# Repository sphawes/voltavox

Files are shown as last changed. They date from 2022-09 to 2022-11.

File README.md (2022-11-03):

# Voltavox
Voltavox is a PCB-based phonograph "badge"!

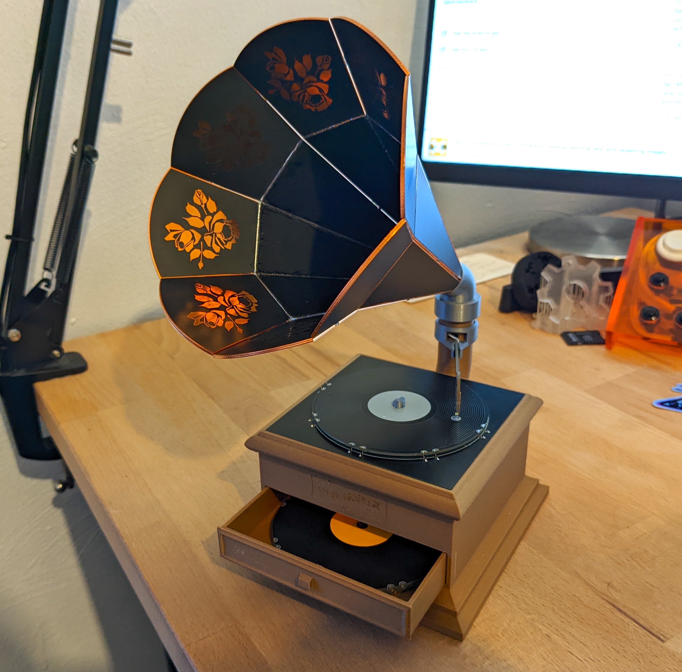
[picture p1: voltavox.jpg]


Made primarially from PCBs, you can take a tiny PCB record, place it on the platter, place the needle on the record, and a song begins to play! Put a different record on, and as expected, you'll get a different song.

Voltavox is based heavily on the [Adafruit Audio FX Sound Board](https://www.adafruit.com/product/2217). Using [arturo182](https://github.com/arturo182)'s [FlexyPins](https://lectronz.com/products/flexypin-pack-of-100) and some castellated edges on the record PCBs, each record selectively pulls a different control pin on the Audio FX board to ground, choosing a different track. Dropping the needle onto the record completes the circuit and starts playing the audio. 
The horn is also comprised of PCBs soldered edge-to-edge, with a small speaker inside.

## BOM
### Off The Shelf
| Item | Quantity |
| ---- | --- |
| [Adafruit Audio FX Sound Board + 2x2W Amp - 16MB](https://www.adafruit.com/product/2217) | 1 |
| [8 Ohm Speaker](https://www.adafruit.com/product/1890) | 1 |
| [1200mAh LiPo Battery](https://www.adafruit.com/product/258) | 1 |
| [Micro-Lipo Charger](https://www.adafruit.com/product/1904) | 1 |
| [FlexyPins](https://lectronz.com/products/flexypin-pack-of-100) | 10 |
| [SPST Slide Switch](https://www.adafruit.com/product/805) | 1 |
| [Silicone Wire - 30AWG](https://www.adafruit.com/product/3169) | 1 |
| [P75-LM3 Spring Pin](https://www.adafruit.com/product/394) | 1 |
| [1x14 2.54mm SMT Header](https://www.digikey.com/en/products/detail/w%C3%BCrth-elektronik/61001418221/4846817) | 2 |
| [1x4 2.54mm SMT Header](https://www.digikey.com/en/products/detail/metz-connect-usa-inc/PM20204VBNN/12342877) | 1 |
| [Adhesive-Backed Green Felt](https://amzn.to/3xrK0NY) | 1 |
| [Dark Wood PLA Filament](https://amzn.to/3QOZQca) | 1 |
| [Record Label Stickers](https://www.amazon.com/dp/B06VX94JD8)| 1 |

### PCBs
| Item | Quantity | Order Instructions | Note |
| ---- | --- | --- | ---- |
| Record | 1+ | 1.6mm PCB, 1oz copper. Gloss Black Soldermask, Lead-Free HASL finish. | Has castellated pads to interface with the FlexyPins. Be sure to include a note to your board shop. | 
| Platter | 1 | 1.6mm PCB, 1oz copper. Matte Black Soldermask, Lead-Free HASL finish. | - |
| Needle | 1 | 1.6mm PCB, 1oz copper. Gloss Black Soldermask, Lead-Free HASL finish. | - |
| Horn Tier 1 | 8 | 1.6mm PCB, 1oz copper. Matte Black Soldermask, ENIG gold immersion finish. | Has castellated edges that are used for structural soldering. Be sure to include a note to your board shop.|
| Horn Tier 2 | 8 | 1.6mm PCB, 1oz copper. Matte Black Soldermask, ENIG gold immersion finish. | Has castellated edges that are used for structural soldering. Be sure to include a note to your board shop.|

### 3D Prints
| Item | Quantity | Material | Note |
| ---- | --- | --- | ---- |
| base | 1 | Wood PLA | Print with supports at 0.2mm layer height, 15% infill or more |
| horn-base-adapter | 1 | Silver PLA | Print with supports at 0.2mm layer height, 20% infill or more |
| drawer | 1 | Wood PLA | Print without supports at 0.2mm layer height, 15% infill or more |
| needle-mount | 1 | Silver PETG | Print without supports at 0.2mm layer height, 20% infill or more |
| pin | 1 | Silver PLA | Print without supports at 0.2mm layer height, 15% infill or more |

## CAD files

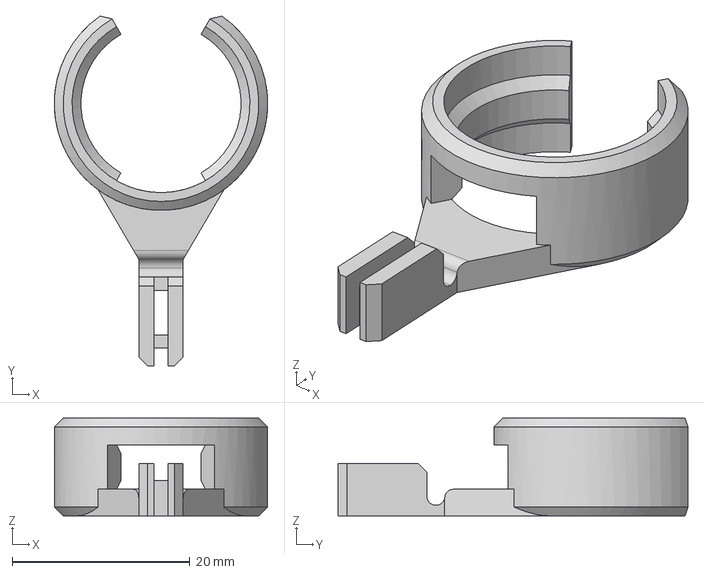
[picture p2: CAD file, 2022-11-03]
3d-prints/needle-mount.step
24.0 x 39.4 x 11.0 mm

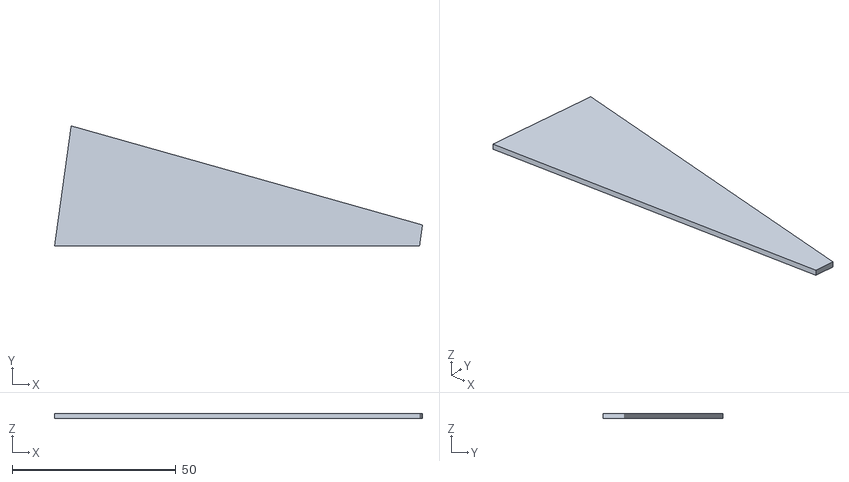
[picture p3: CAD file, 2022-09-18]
pcb/horn/tier1testprint.stl
112.4 x 36.7 x 1.60

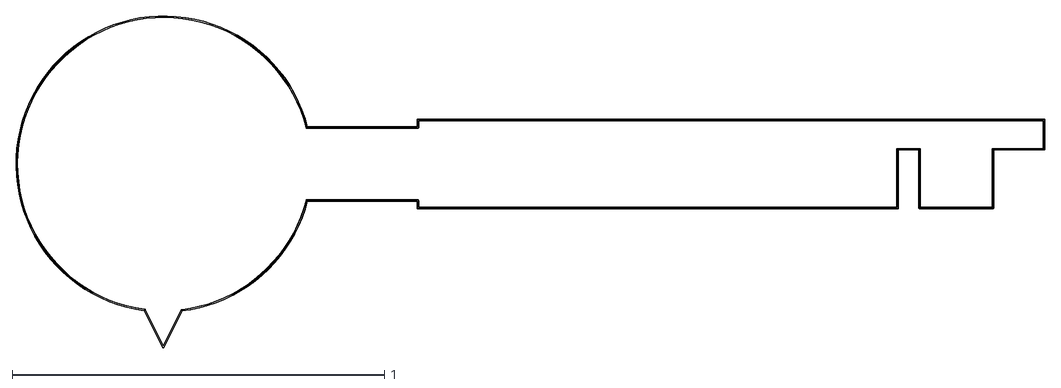
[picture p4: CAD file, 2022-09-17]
pcb/needle/Volta_Needle-Edge_Cuts.dxf
2.77 x 0.892

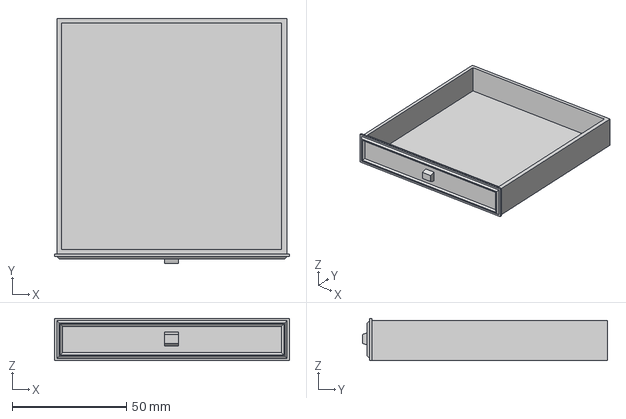
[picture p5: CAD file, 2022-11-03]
3d-prints/drawer.step
103.0 x 107.2 x 18.5 mm

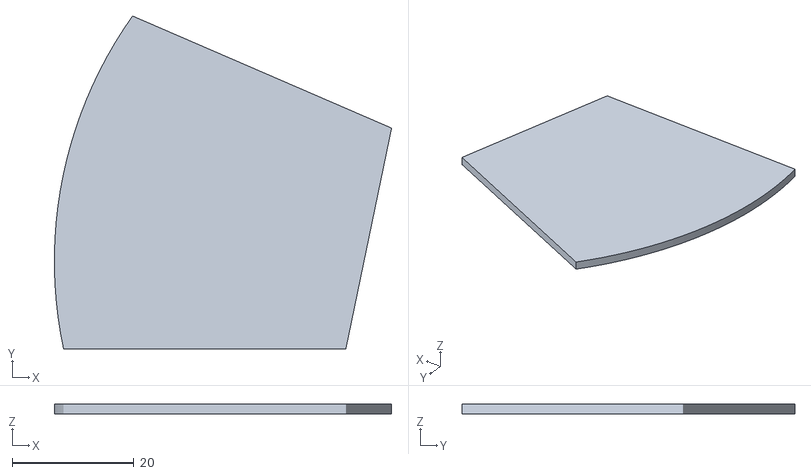
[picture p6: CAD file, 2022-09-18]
pcb/horn/tier2testprint.stl
55.4 x 54.7 x 1.60

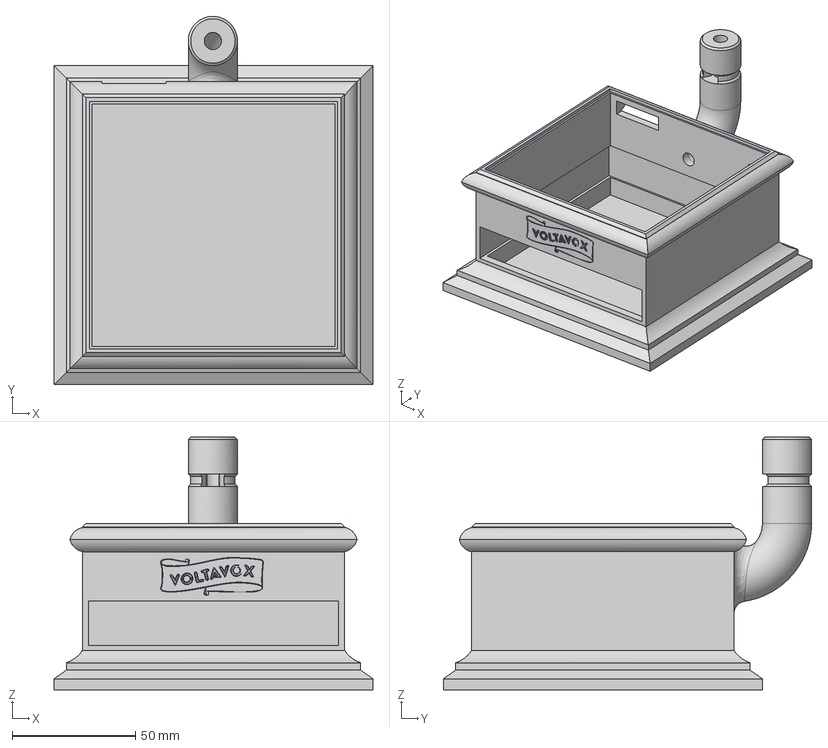
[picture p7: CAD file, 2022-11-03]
3d-prints/base.step
129.5 x 149.5 x 102.6 mm

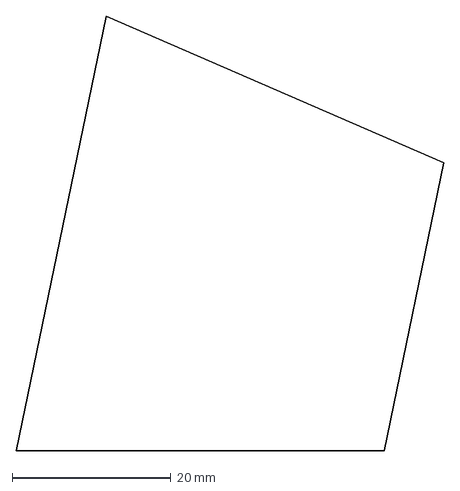
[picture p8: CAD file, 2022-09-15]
pcb/horn/tier2_shape.dxf
53.9 x 54.7 mm

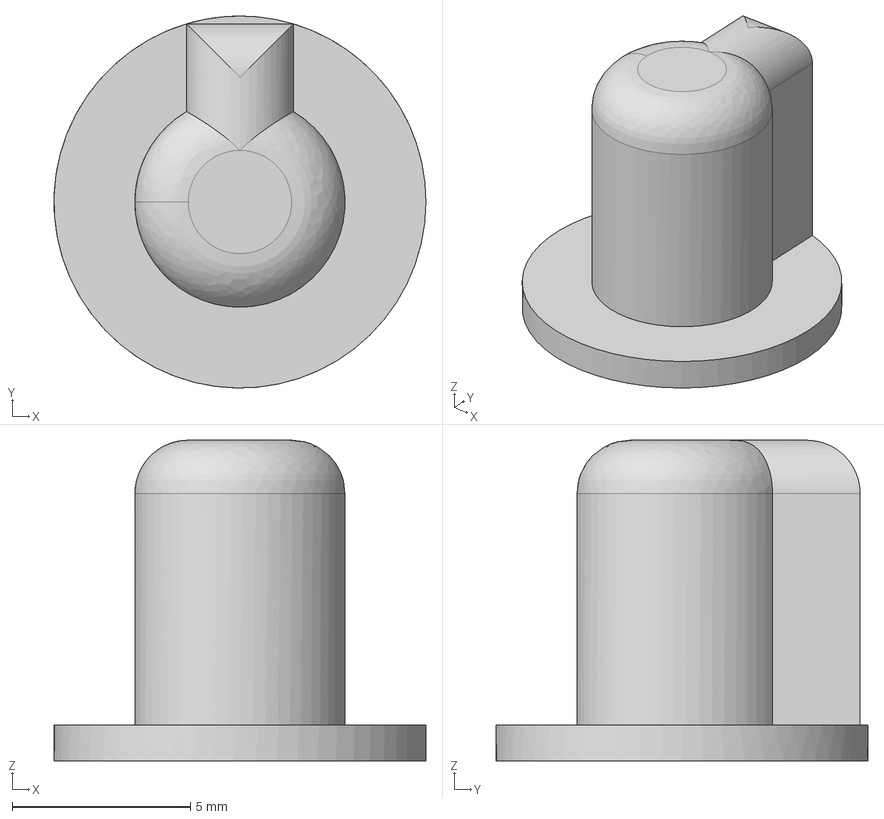
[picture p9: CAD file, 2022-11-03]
3d-prints/pin.step
10.4 x 10.4 x 9.00 mm

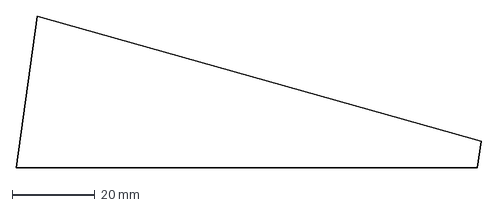
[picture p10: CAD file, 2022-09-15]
pcb/horn/tier1_shape.dxf
112.4 x 36.7 mm

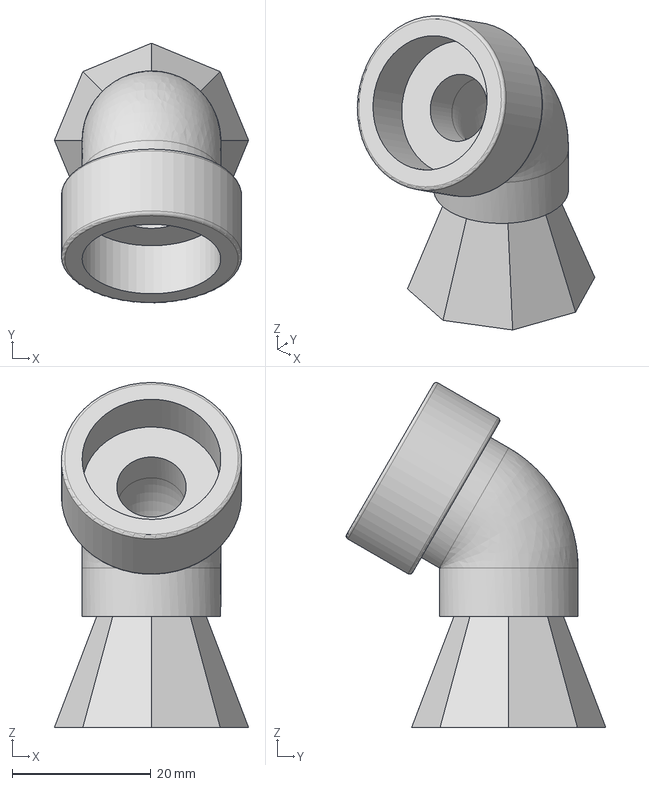
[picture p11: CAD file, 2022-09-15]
3d-prints/horn-base-adapter.step
28.0 x 37.4 x 49.7 mm

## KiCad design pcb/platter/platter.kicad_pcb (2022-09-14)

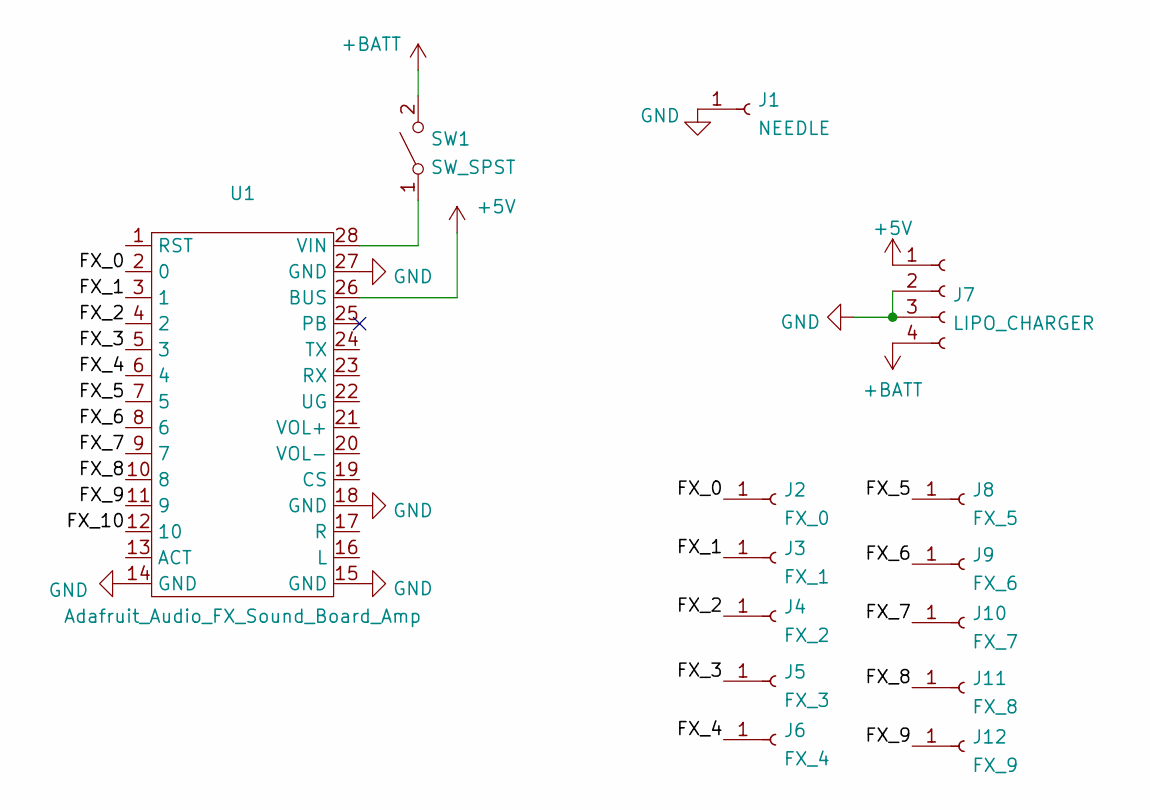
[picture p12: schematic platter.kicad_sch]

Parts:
J1: NEEDLE; TestPoint_Pad_D2.0mm
J2: FX_0; FlexyPin_1x01_P2.54mm
J3: FX_1; FlexyPin_1x01_P2.54mm
J4: FX_2; FlexyPin_1x01_P2.54mm
J5: FX_3; FlexyPin_1x01_P2.54mm
J6: FX_4; FlexyPin_1x01_P2.54mm
J7: LIPO_CHARGER; PinHeader_1x04_P2.54mm_Vertical_SMD_Pin1Left
J8: FX_5; FlexyPin_1x01_P2.54mm
J9: FX_6; FlexyPin_1x01_P2.54mm
J10: FX_7; FlexyPin_1x01_P2.54mm
J11: FX_8; FlexyPin_1x01_P2.54mm
J12: FX_9; FlexyPin_1x01_P2.54mm
SW1: SW_SPST; SolderJumper-2_P1.3mm_Open_Pad1.0x1.5mm
U1: Adafruit_Audio_FX_Sound_Board_Amp; Adafruit_Audio_FX_Board

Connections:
+5V: J7.1, U1.26 (BUS)
+BATT: J7.4, SW1.2 (B)
/FX_0: J2.1, U1.2 (0)
/FX_1: J3.1, U1.3 (1)
/FX_2: J4.1, U1.4 (2)
/FX_3: J5.1, U1.5 (3)
/FX_4: J6.1, U1.6 (4)
/FX_5: J8.1, U1.7 (5)
/FX_6: J9.1, U1.8 (6)
/FX_7: J10.1, U1.9 (7)
/FX_8: J11.1, U1.10 (8)
/FX_9: J12.1, U1.11 (9)
/FX_10: U1.12 (10)
GND: J1.1, J7.2, J7.3, U1.14 (GND), U1.15 (GND), U1.18 (GND), U1.27 (GND)
unnamed: SW1.1 (A), U1.28 (VIN)

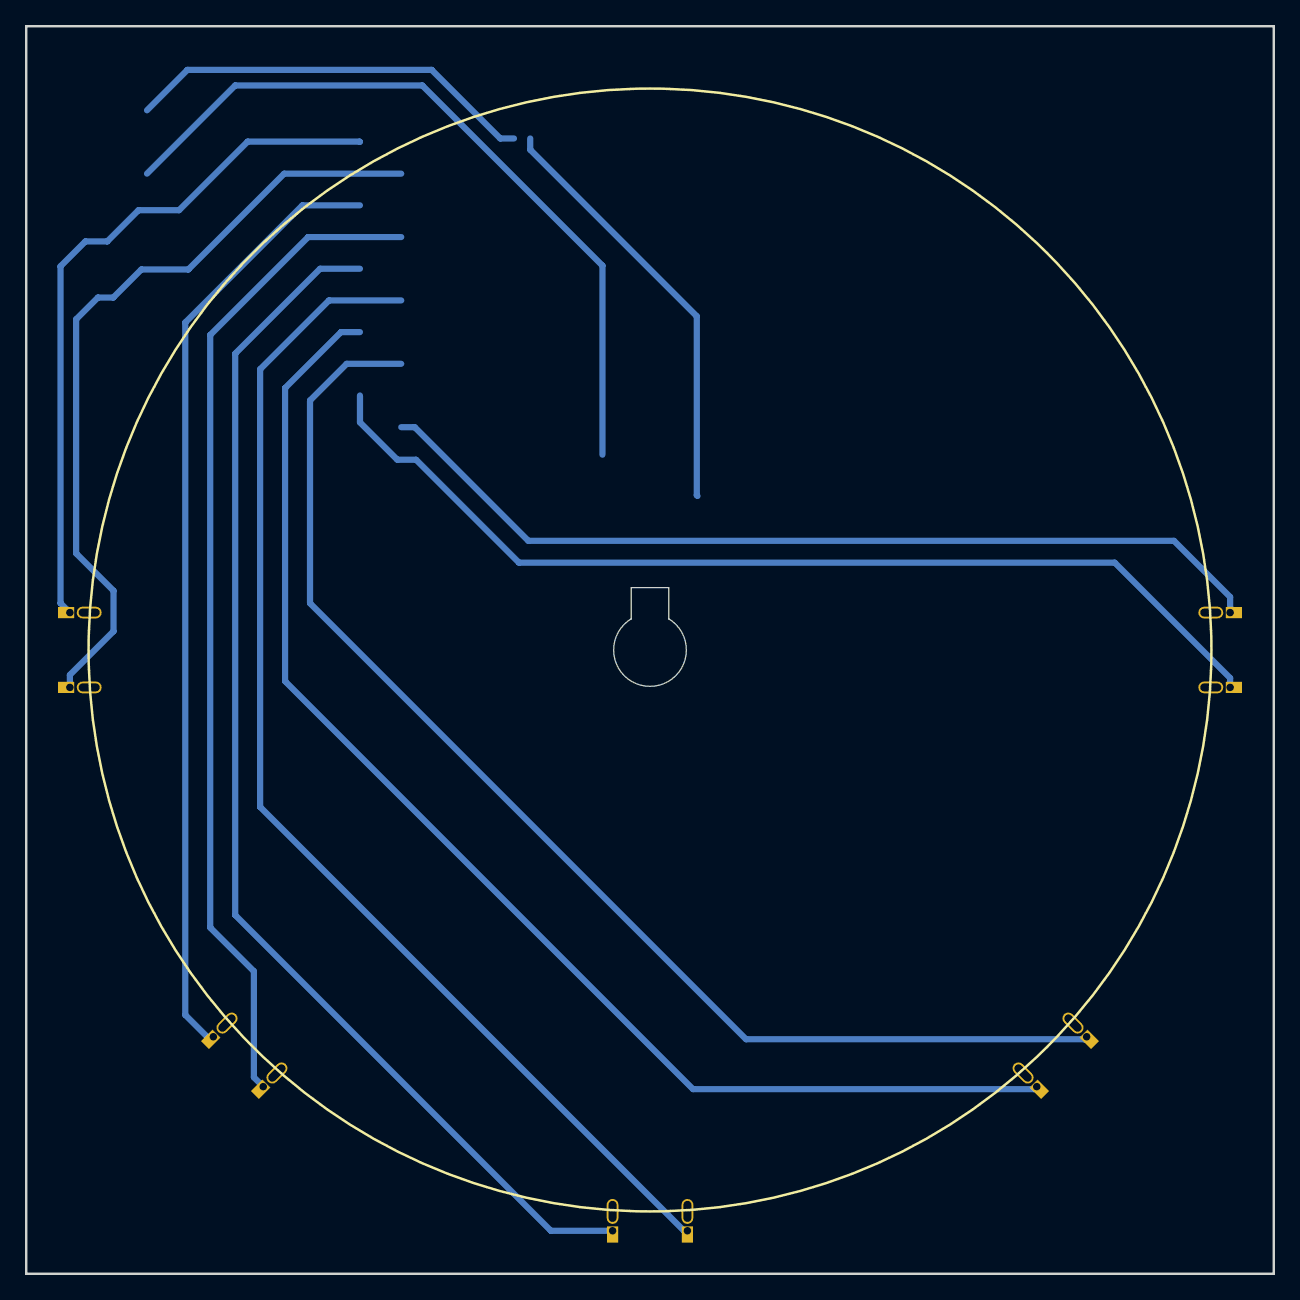
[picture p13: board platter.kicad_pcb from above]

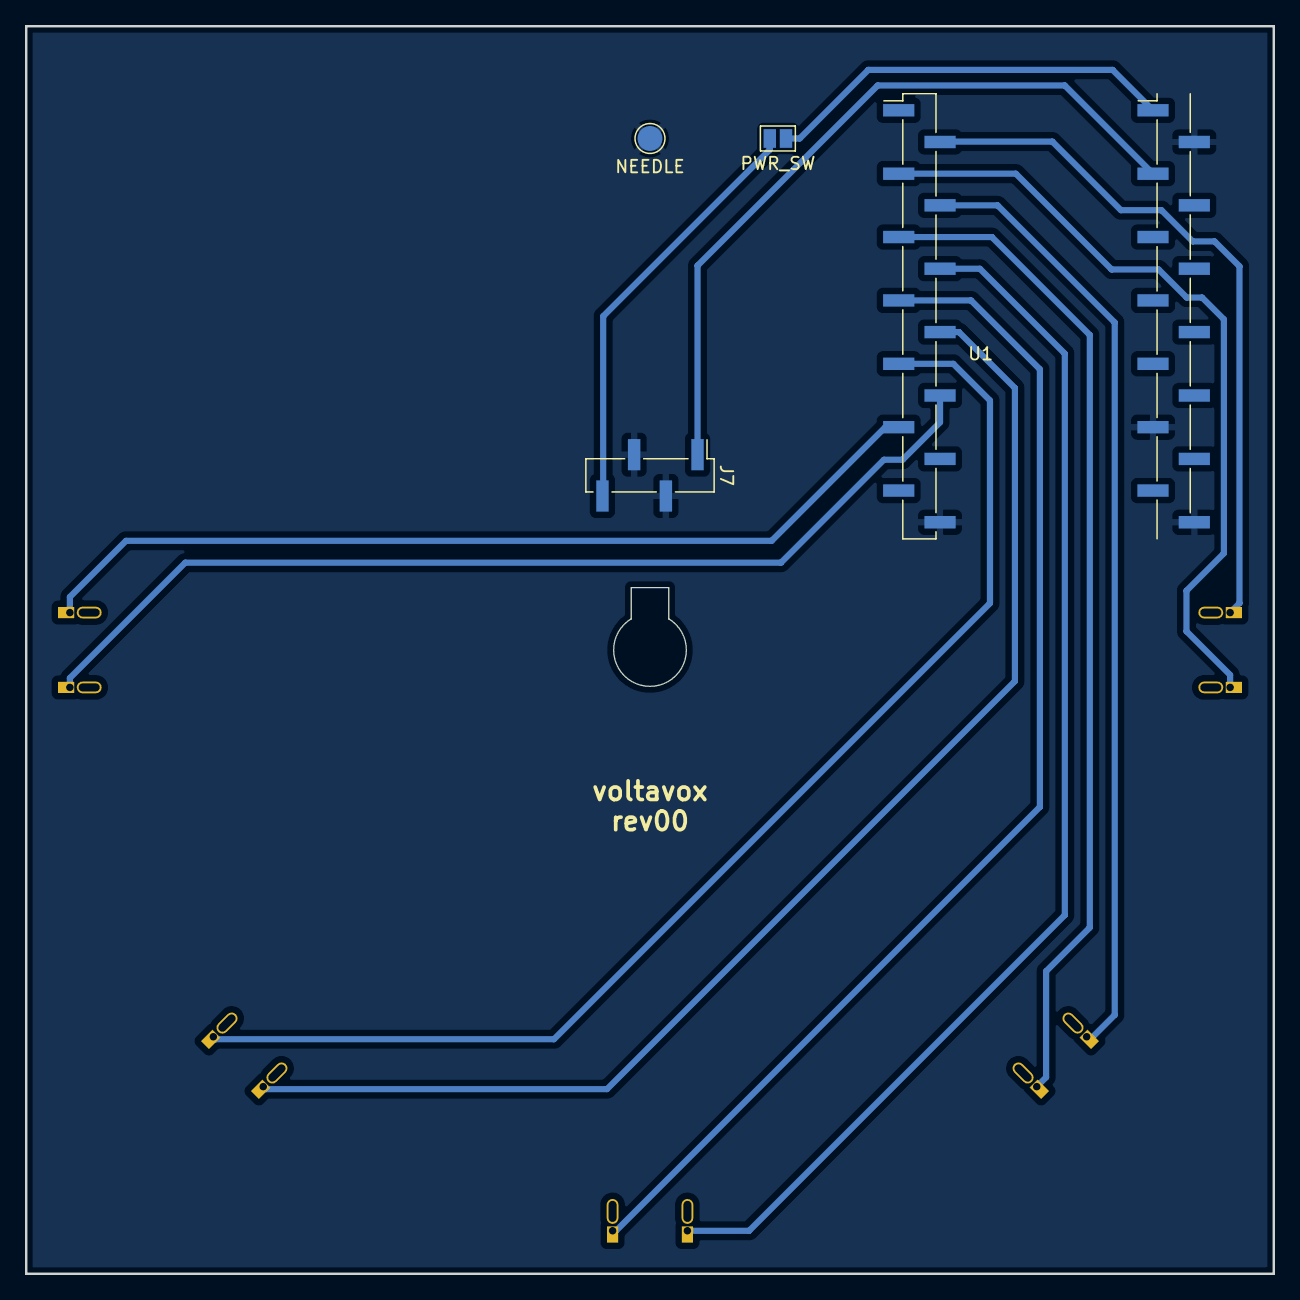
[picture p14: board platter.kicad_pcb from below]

Board: 2 copper layers, 100.0 x 100.0 mm, 14 parts (4 on the bottom side), 14 nets.

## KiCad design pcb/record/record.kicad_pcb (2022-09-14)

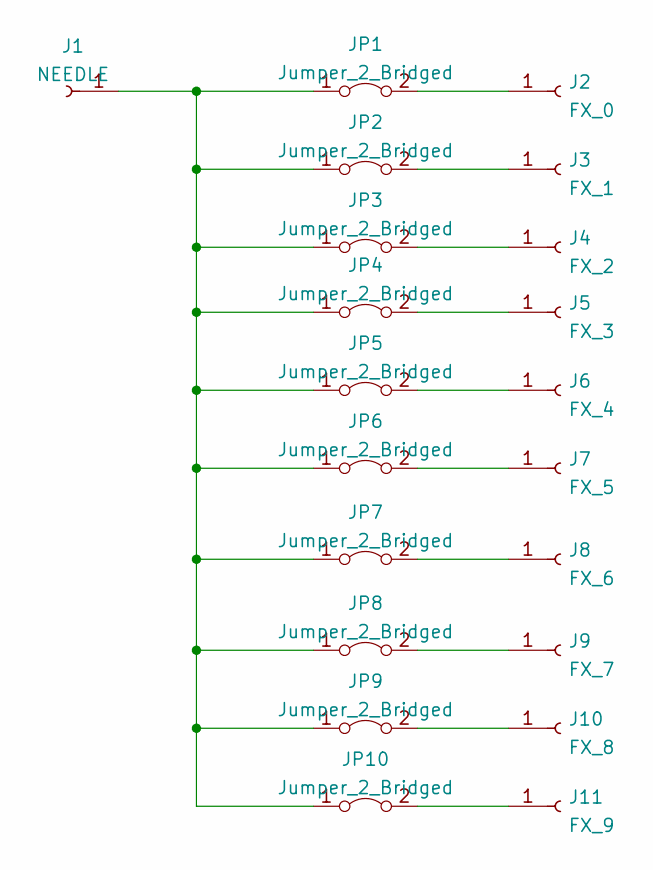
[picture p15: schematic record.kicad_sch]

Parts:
J1: NEEDLE; TestPoint_Pad_D4.0mm
J2: FX_0; TestPoint_Loop_D2.50mm_Drill1.0mm_LowProfile
J3: FX_1; TestPoint_Loop_D2.50mm_Drill1.0mm_LowProfile
J4: FX_2; TestPoint_Loop_D2.50mm_Drill1.0mm_LowProfile
J5: FX_3; TestPoint_Loop_D2.50mm_Drill1.0mm_LowProfile
J6: FX_4; TestPoint_Loop_D2.50mm_Drill1.0mm_LowProfile
J7: FX_5; TestPoint_Loop_D2.50mm_Drill1.0mm_LowProfile
J8: FX_6; TestPoint_Loop_D2.50mm_Drill1.0mm_LowProfile
J9: FX_7; TestPoint_Loop_D2.50mm_Drill1.0mm_LowProfile
J10: FX_8; TestPoint_Loop_D2.50mm_Drill1.0mm_LowProfile
J11: FX_9; TestPoint_Loop_D2.50mm_Drill1.0mm_LowProfile
JP1, JP2, JP3, JP4, JP5, JP6, JP7, JP8, JP9, JP10: Jumper_2_Bridged; SolderJumper-2_P1.3mm_Bridged_RoundedPad1.0x1.5mm

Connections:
unnamed: J1.1, JP1.1 (A), JP2.1 (A), JP3.1 (A), JP4.1 (A), JP5.1 (A), JP6.1 (A), JP7.1 (A), JP8.1 (A), JP9.1 (A), JP10.1 (A)
unnamed: J2.1, JP1.2 (B)
unnamed: J3.1, JP2.2 (B)
unnamed: J4.1, JP3.2 (B)
unnamed: J5.1, JP4.2 (B)
unnamed: J6.1, JP5.2 (B)
unnamed: J7.1, JP6.2 (B)
unnamed: J8.1, JP7.2 (B)
unnamed: J9.1, JP8.2 (B)
unnamed: J10.1, JP9.2 (B)
unnamed: J11.1, JP10.2 (B)

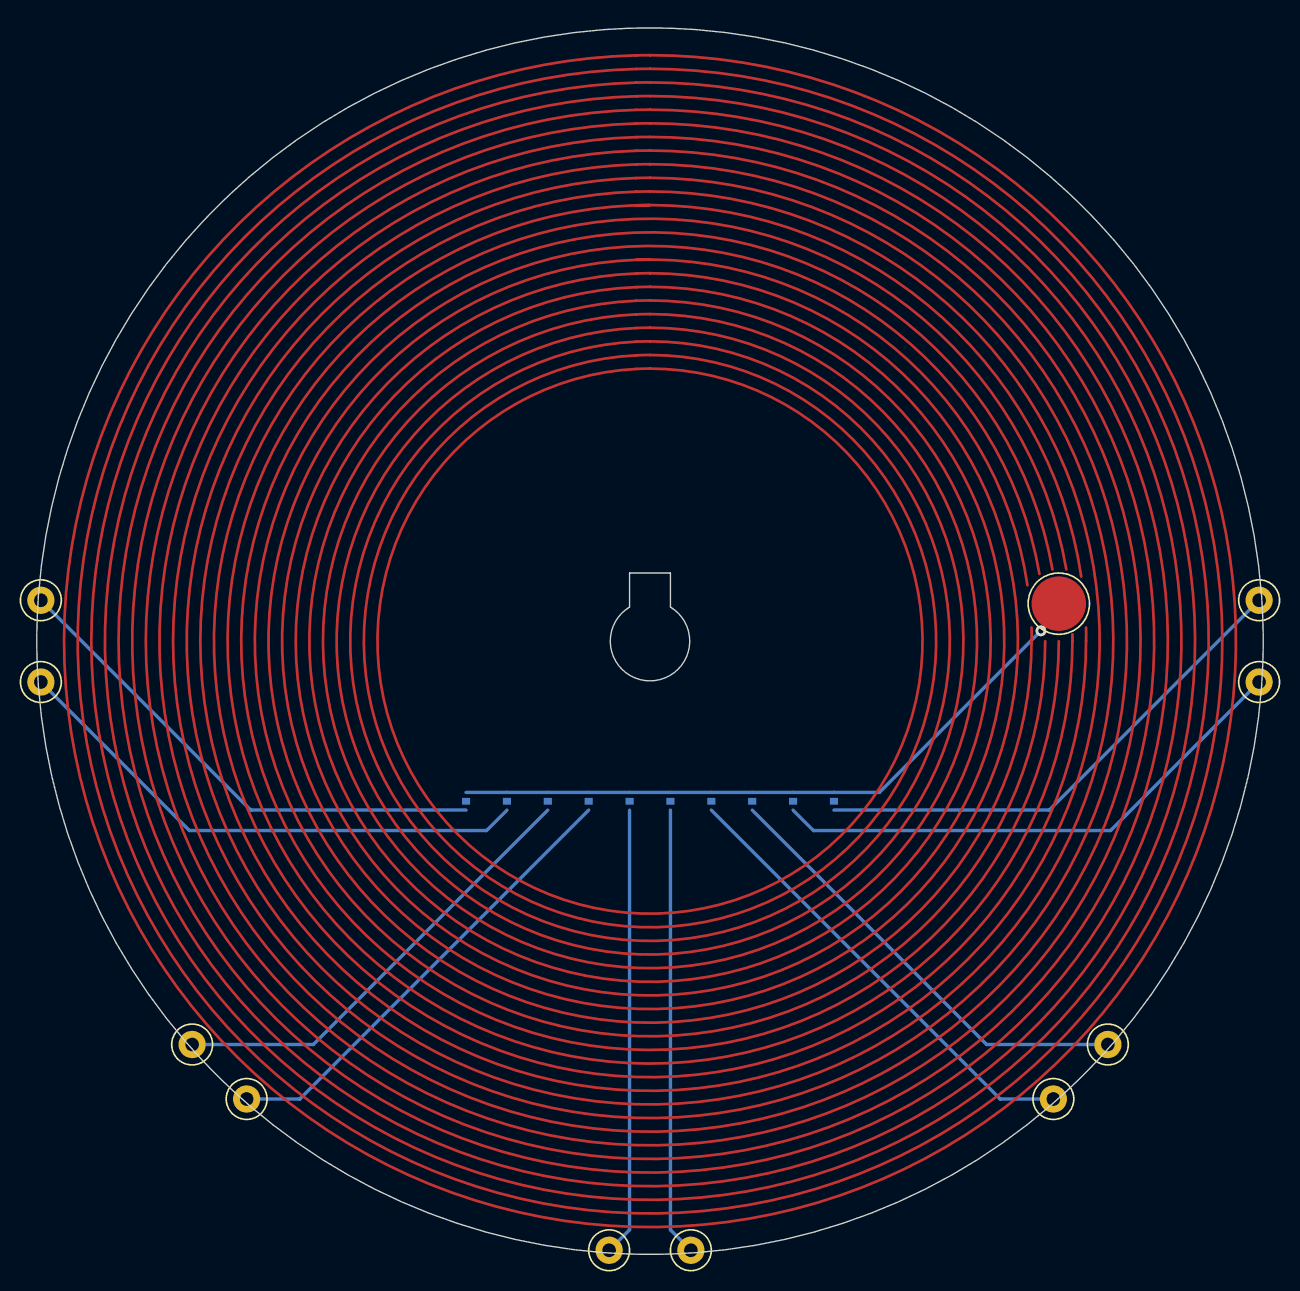
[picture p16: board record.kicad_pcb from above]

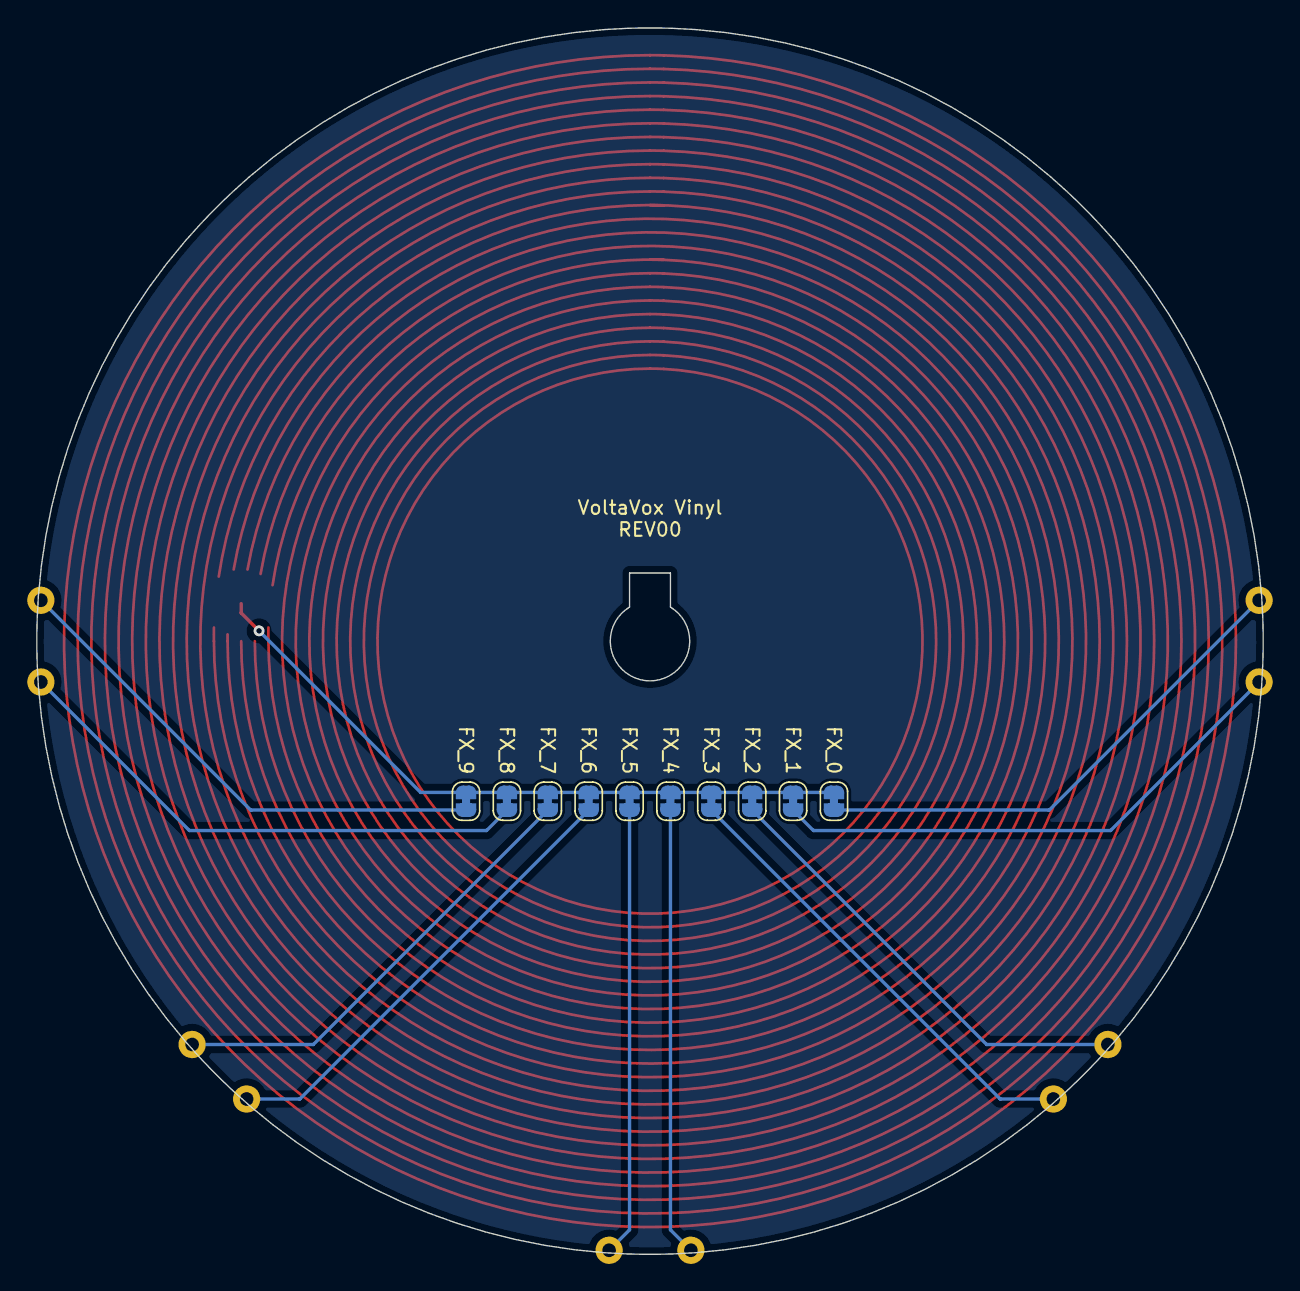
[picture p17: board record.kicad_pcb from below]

Board: 2 copper layers, 90.0 x 90.0 mm, 21 parts (10 on the bottom side), 11 nets.

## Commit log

2022-09-14 adds bom to readme, adds platter and record pcbs
    [platter-B_Cu.gbr, platter-B_Mask.gbr, platter-B_Paste.gbr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]
2022-09-15 adds horn-base-adapter files
    connects phonograph horn PCB panels to wire channel.
    [horn-base-adapter.step, horn-base-adapter.stl]
2022-09-15 adds voltavox box graphic
    a new folder with the .ai and .svg of a vector graphic for the box
2022-09-15 updates internal dimensions of horn-base-adapter
    test print didn't fit. this is an alteration of the interior diameter of the wire channel.
    [horn-base-adapter.step, horn-base-adapter.stl]
2022-09-15 adds pcb outlines for horn component
    [tier1_shape.dxf, tier2_shape.dxf]
2022-09-15 moves needle pcb into repository
    this will need rework, but belongs in this repo for now.
    [Volta_Needle.kicad_pcb, Volta_Needle.kicad_sch]
2022-09-17 changes volta needle to spec
    [Volta_Needle.kicad_pcb]
2022-09-17 updates length of needle pcb
    [Volta_Needle-Edge_Cuts.dxf, Volta_Needle.kicad_pcb]
2022-09-17 updates length of needle pcb
    again
    [Volta_Needle-Edge_Cuts.dxf, Volta_Needle.kicad_pcb]
2022-09-18 tweaks aesthetic things about the horn pcbs
    send Rev0 to JLC for manufacturing
    [Volta_Needle-B_Cu.gbr, Volta_Needle-B_Mask.gbr, Volta_Needle-B_Silkscreen.gbr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]
2022-09-18 fixes folder pathways
    [tier2-B_Cu.gbr, tier2-B_Mask.gbr, tier2-B_Paste.gbr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]
2022-09-19 adds zipped folders for pcb production
    [tier2.kicad_pcb]
2022-10-10 adjusts adapter and adds jigv1
    [horn-base-adapter2.stl, horn-base-adapter3.stl, hornjig.stl]
2022-10-11 adds step file of horn
    [horn-base-adapter v2.step]
2022-11-03 adds record stickers to bom, changes horn base adapter to silver pla, adds pic
2022-11-03 adds marvelous party track
    i couldn't've liked it more!
2022-11-03 Fixing track 00
2022-11-03 cleans up cad files, updates readme to include pin
    [base.step, drawer.step, horn-base-adapter v2.step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]
2022-11-03 suggesting supports for base print
